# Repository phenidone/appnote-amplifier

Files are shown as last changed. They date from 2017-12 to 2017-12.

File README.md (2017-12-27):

# appnote-amplifier

This is a PCB design for a headphone amplifier based on the example schematic in the LME49600 datasheet.

## Power Supply

You will need a 12VAC or 24VAC centre-tapped transformer.  The simplest/safest option is to use it with
a Class-II (double insulated) accredited 12VAC 0.5A plugpack and not ground any part of this design.

Use Phoenix-style screw terminals.

## Inputs & Outputs

Place a 10K dual-gang A-scale volume pot between the signal source and the inputs to this board.  Use 0.1"-pitch
Phoenix-style screw terminals.

## Thermal

There is a bare patch on the board surrounding the output stage; you can solder a strip of copper
sheet here to act as a heatsink, if that seems to be necessary (almost certainly not).  Note that it will be connected to the negative
rail, so don't let the heatsink touch anything.

## Errata

Rev.A is missing reverse-protection diodes around the regulators.  They are considered best-practise
for cases where the input voltage on a regulator may collapse faster than its output and as such should not be necessary for this design - the regulators should be the only current
drain upon the rectifier capacitors.  They have been added to Rev.B on the basis of paranoia and can be hand-soldered onto the underside of a Rev.A board.

The BOM lists 7812 and 7912 regulators and 12VAC supply, which is more voltage than most headphones require.  For headphones of no more than 64 ohms,
a 7805 and 7905 are enough and will need only a 6VAC transformer.

## License

This hardware design is (C) 2017 William Brodie-Tyrrell and is licensed under the CERN OHL; see cern_ohl_v_1_2.pdf

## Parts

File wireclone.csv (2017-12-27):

Reference | Value | Footprint | Datasheet
P3 | CONN_01X03 | Pin_Headers:Pin_Header_Straight_1x03_Pitch2.54mm
P2 | CONN_01X02 | Pin_Headers:Pin_Header_Straight_1x02_Pitch2.54mm
P4 | CONN_01X02 | Pin_Headers:Pin_Header_Straight_1x02_Pitch2.54mm
FID1 | FIDUCIAL | smd:FID0.5
FID2 | FIDUCIAL | smd:FID0.5
FID4 | FIDUCIAL | smd:FID0.5
FID3 | FIDUCIAL | smd:FID0.5
U1 | LME49720 | Housings_DIP:DIP-8_W7.62mm_Socket
R1 | 1k | Resistors_SMD:R_0805
R9 | 1k | Resistors_SMD:R_0805
R7 | 1k | Resistors_SMD:R_0805
C7 | 1u | Capacitors_SMD:C_0805
R2 | 1M | Resistors_SMD:R_0805
R5 | 1M | Resistors_SMD:R_0805
C3 | 1u | Capacitors_SMD:C_1206
C4 | 1u | Capacitors_SMD:C_1206
C1 | 1u | Capacitors_SMD:C_0805
U4 | LME49600 | power:TO-263-5
U2 | LME49720 | Housings_DIP:DIP-8_W7.62mm_Socket
R3 | 1k | Resistors_SMD:R_0805
R10 | 1k | Resistors_SMD:R_0805
R8 | 1k | Resistors_SMD:R_0805
C8 | 1u | Capacitors_SMD:C_0805
R4 | 1M | Resistors_SMD:R_0805
R6 | 1M | Resistors_SMD:R_0805
C5 | 1u | Capacitors_SMD:C_1206
C6 | 1u | Capacitors_SMD:C_1206
C2 | 1u | Capacitors_SMD:C_0805
C9 | 10u | Capacitors_SMD:C_1206
C10 | 10u | Capacitors_SMD:C_1206
C11 | 10u | Capacitors_SMD:C_1206
C12 | 10u | Capacitors_SMD:C_1206
U3 | LME49600 | power:TO-263-5
D1 | M7 | Diodes_SMD:D_SMA
D2 | M7 | Diodes_SMD:D_SMA
C17 | 1000u | Capacitors_ThroughHole:C_Radial_D16_L25_P7.5
C19 | 1000u | Capacitors_ThroughHole:C_Radial_D16_L25_P7.5
C21 | 100n | Capacitors_SMD:C_0805
C18 | 1000u | Capacitors_ThroughHole:C_Radial_D16_L25_P7.5
C20 | 1000u | Capacitors_ThroughHole:C_Radial_D16_L25_P7.5
C22 | 100n | Capacitors_SMD:C_0805
U5 | LM7812CT | Power_Integrations:TO-220
U6 | LM7912CT | Power_Integrations:TO-220
P1 | CONN_01X03 | Terminals_Phoenix:TerminalBlock_Phoenix_MPT-2.54mm_3pol
D4 | M7 | Diodes_SMD:D_SMA
D3 | M7 | Diodes_SMD:D_SMA
D5 | M7 | Diodes_SMD:D_SMA
D6 | M7 | Diodes_SMD:D_SMA

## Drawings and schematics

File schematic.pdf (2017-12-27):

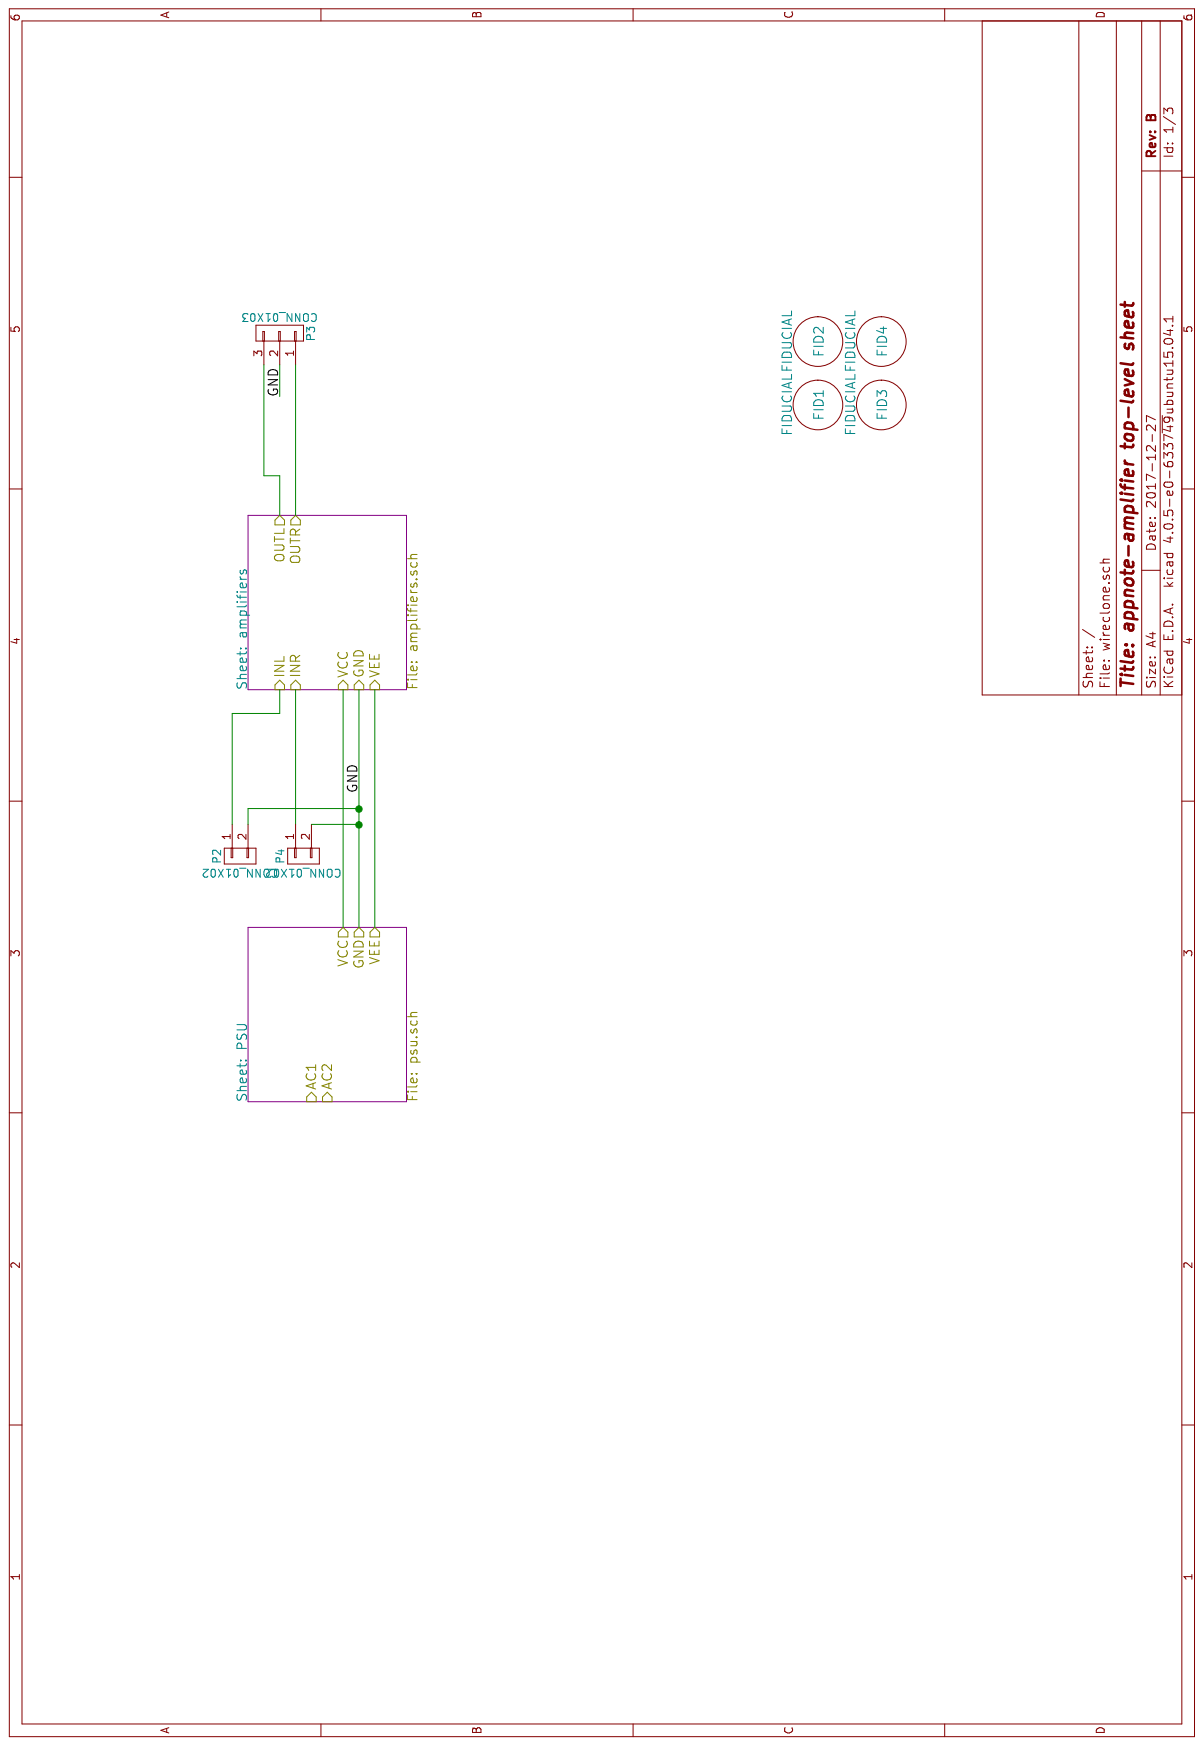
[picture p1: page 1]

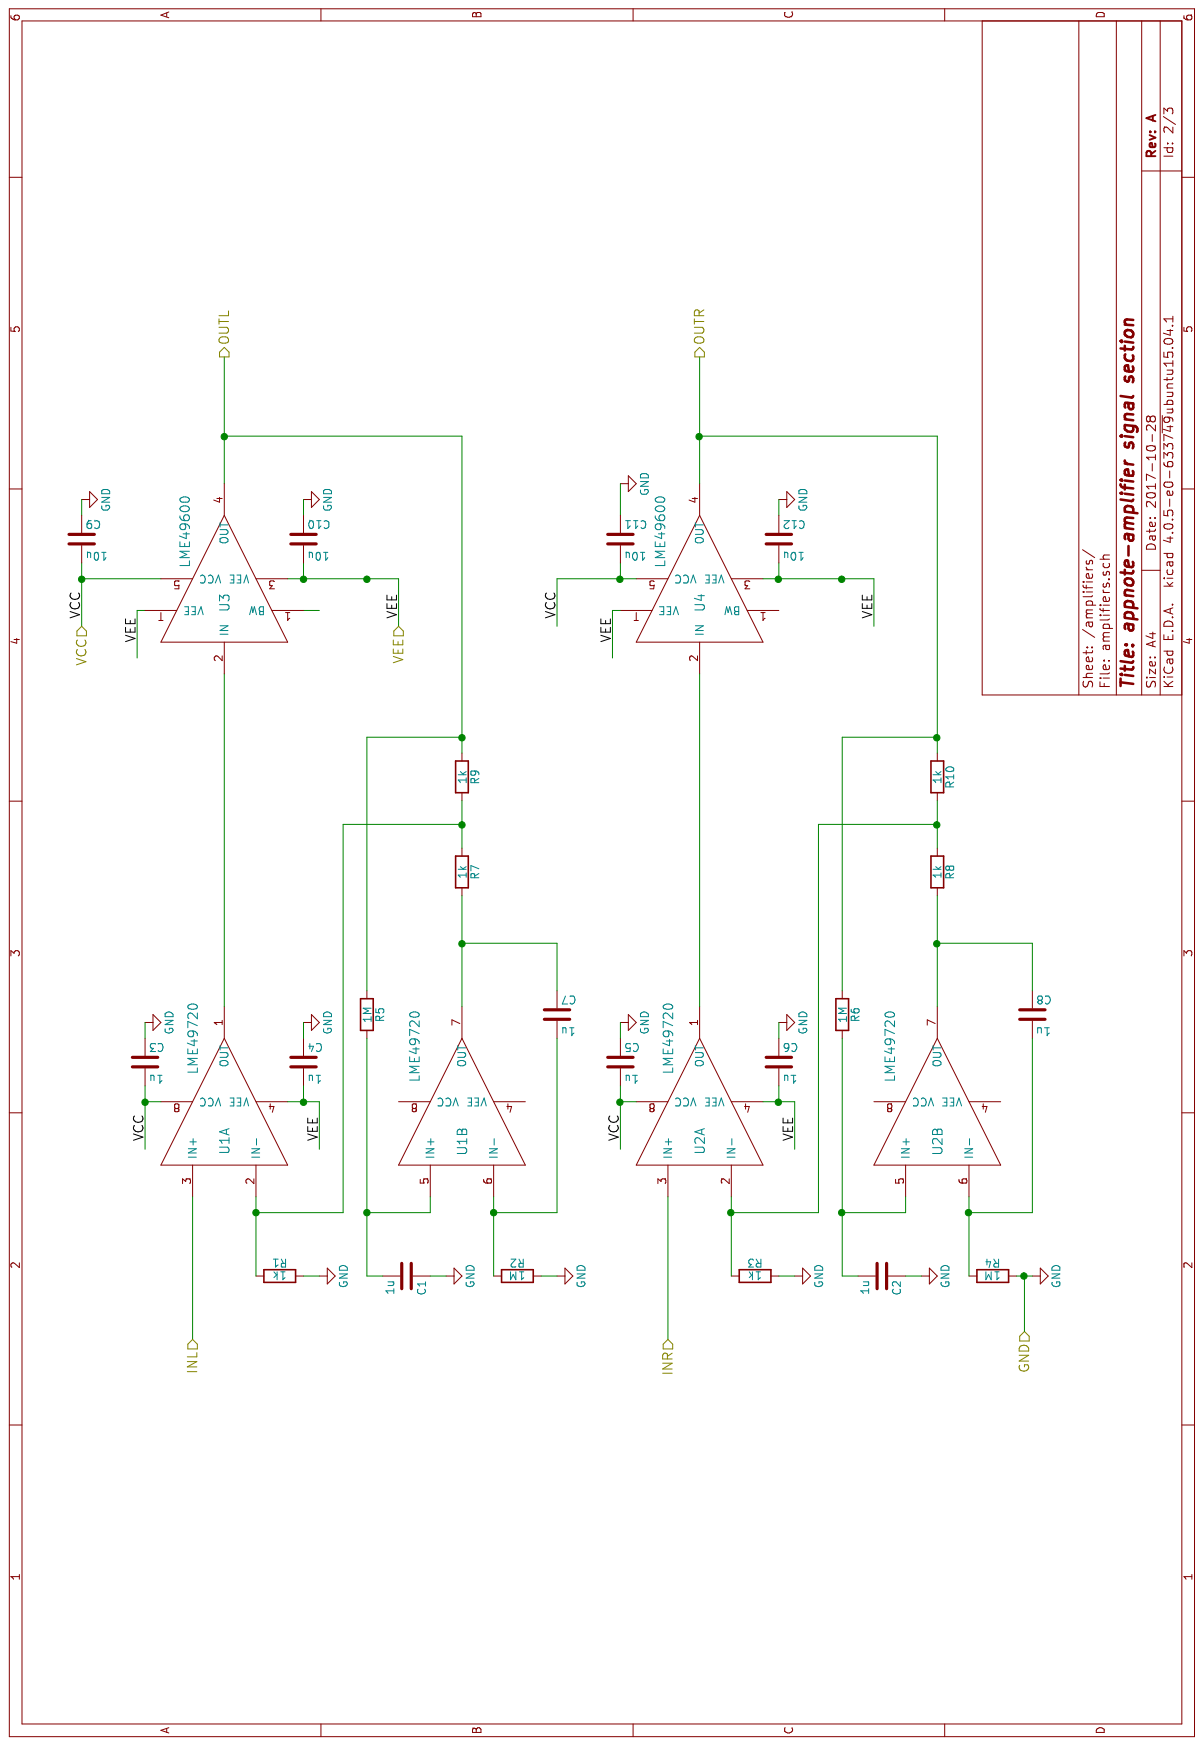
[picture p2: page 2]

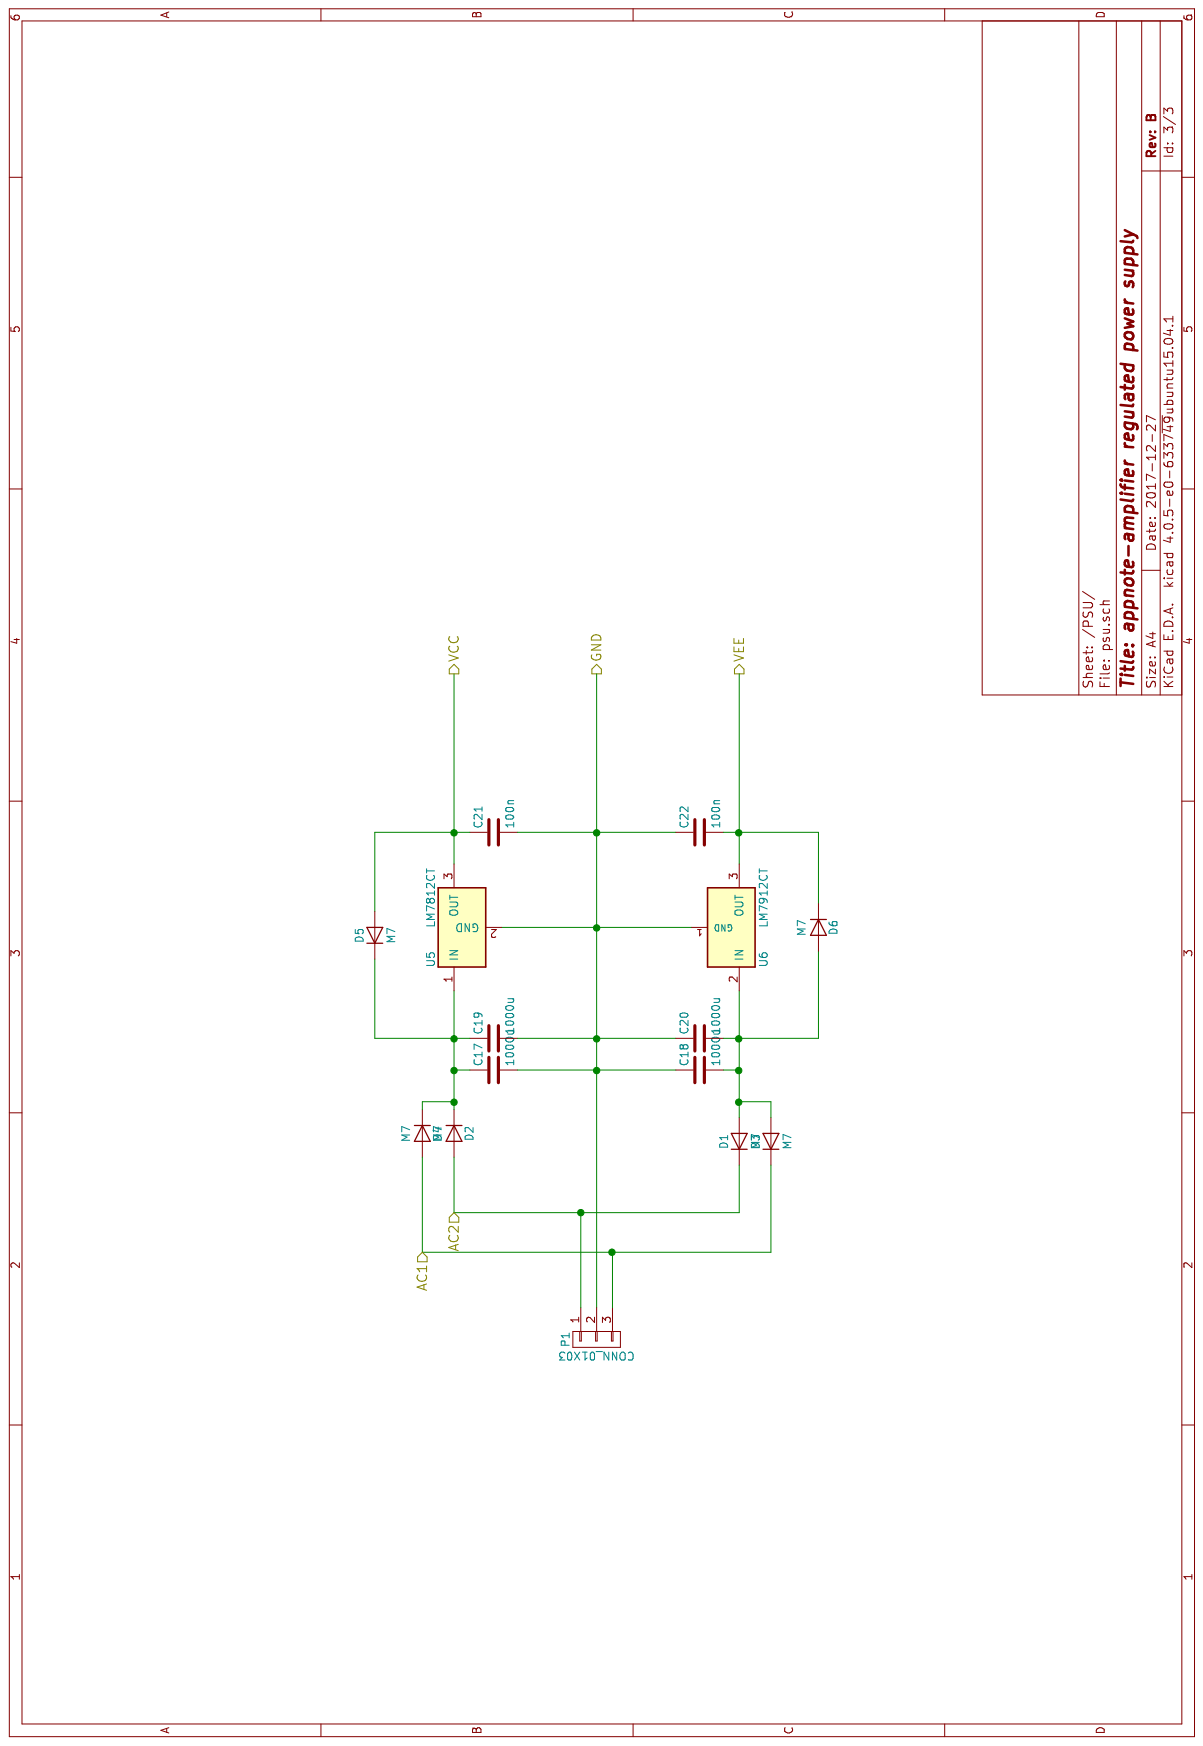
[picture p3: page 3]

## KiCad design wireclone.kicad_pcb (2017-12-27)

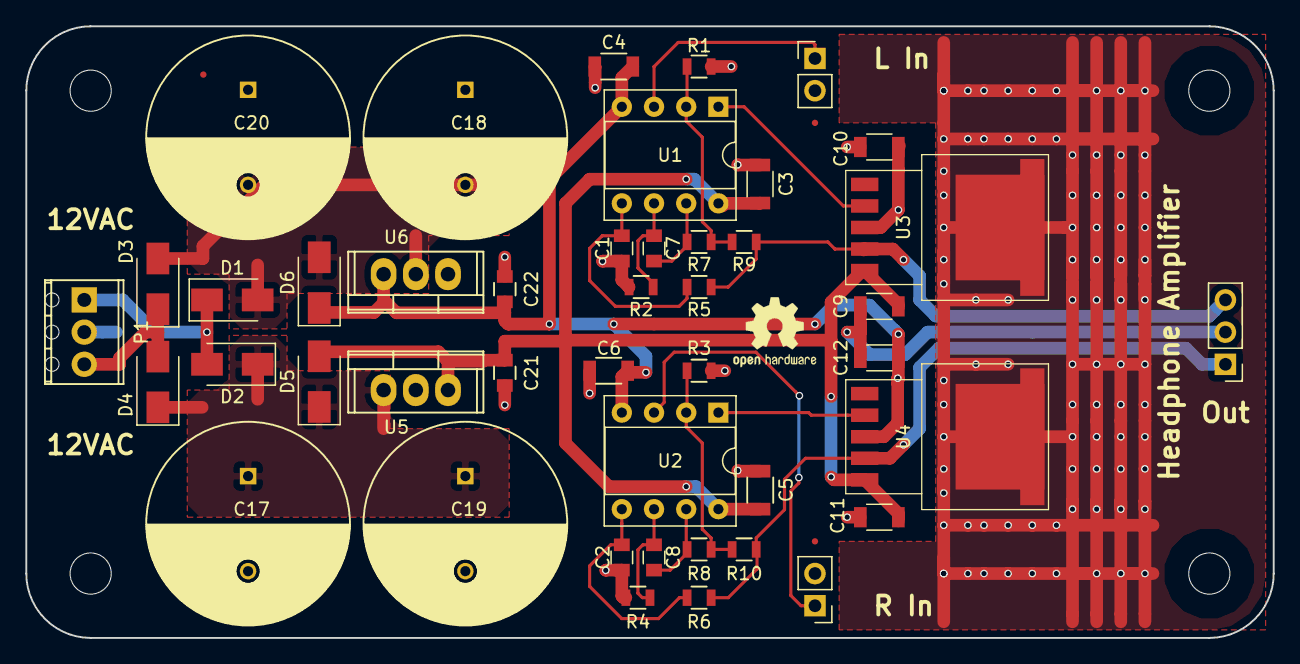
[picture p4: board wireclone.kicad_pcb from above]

Board: 2 copper layers, 98.4 x 48.3 mm, 48 parts (0 on the bottom side), 21 nets.

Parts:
C1, C2, C7, C8: 1u; C_0805
C3, C4, C5, C6: 1u; C_1206
C9, C10, C11, C12: 10u; C_1206
C17, C18, C19, C20: 1000u; C_Radial_D16_L25_P7.5
C21, C22: 100n; C_0805
D1, D2, D3, D4, D5, D6: M7; D_SMA
FID1, FID2, FID3, FID4: FIDUCIAL; FID0.5
P1: CONN_01X03; TerminalBlock_Phoenix_MPT-2.54mm_3pol
P2, P4: CONN_01X02; Pin_Header_Straight_1x02_Pitch2.54mm
P3: CONN_01X03; Pin_Header_Straight_1x03_Pitch2.54mm
R1, R3, R7, R8, R9, R10: 1k; R_0805
R2, R4, R5, R6: 1M; R_0805
U1, U2: LME49720; DIP-8_W7.62mm_Socket
U3, U4: LME49600; TO-263-5
U5: LM7812CT; TO-220
U6: LM7912CT; TO-220

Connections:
/PSU/AC1: D3.1, D4.2, P1.3
/PSU/AC2: D1.1, D2.2, P1.1
/PSU/VCC: C3.2, C5.2, C9.2, C11.2, C21.1, D5.2, U1.8, U2.8, U3.5, U4.5, U5.3
/PSU/VEE: C4.2, C6.2, C10.2, C12.2, C22.2, D6.1, U1.4, U2.4, U3.3, U3.T, U4.3, U4.T, U6.3
/amplifiers/INL: P2.1, U1.3
/amplifiers/INR: P4.1, U2.3
/amplifiers/OUTL: P3.3, R5.1, R9.1, U3.4
/amplifiers/OUTR: P3.1, R6.1, R10.1, U4.4
GND: C1.1, C2.1, C3.1, C4.1, C5.1, C6.1, C9.1, C10.1, C11.1, C12.1, C17.2, C18.1, C19.2, C20.1, C21.2, C22.1, P1.2, P2.2, P3.2, P4.2, R1.2, R2.2, R3.2, R4.2, U5.2, U6.1
unnamed: C1.2, R5.2, U1.5
unnamed: C2.2, R6.2, U2.5
unnamed: C7.1, R7.2, U1.7
unnamed: C7.2, R2.1, U1.6
unnamed: C8.1, R8.2, U2.7
unnamed: C8.2, R4.1, U2.6
unnamed: C17.1, C19.1, D2.1, D4.1, D5.1, U5.1
unnamed: C18.2, C20.2, D1.2, D3.2, D6.2, U6.2
unnamed: R1.1, R7.1, R9.2, U1.2
unnamed: R3.1, R8.1, R10.2, U2.2
unnamed: U1.1, U3.2
unnamed: U2.1, U4.2

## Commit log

2016-12-07 begin schematic drafting - follows LME49600 datasheet
    [wireclone.kicad_pcb, wireclone.sch]
2017-10-24 checked in all subsheets
    [wireclone.kicad_pcb, wireclone.sch]
2017-10-24 second try adding
    [amplifiers.sch, psu.sch, xformer.sch]
2017-10-25 did most of the layout
    [amplifiers.sch, psu.sch, wireclone.kicad_pcb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]
2017-10-25 moved output to end, stitched thermal plane
    [wireclone.kicad_pcb, wireclone.sch]
2017-10-26 complete layout drafted
    [amplifiers.sch, wireclone.kicad_pcb, wireclone.sch]
2017-10-26 shortened board
    [wireclone-B.Cu.gbr, wireclone-B.Mask.gbr, wireclone-B.SilkS.gbr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]
2017-10-26 added fiducials
    [wireclone-B.Cu.gbr, wireclone-B.Mask.gbr, wireclone-B.SilkS.gbr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]
2017-10-28 cleanup, rev.a as manufactured
    [wireclone-B.Cu.gbr, wireclone-B.Mask.gbr, wireclone-B.SilkS.gbr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]
2017-10-28 updated readme (grounding)
2017-10-28 added PDF of schematic
    [amplifiers.sch, psu.sch, wireclone.sch]
2017-12-27 added reverse protection diodes to regulators, bumped to Rev.B
    [amplifiers.sch, psu.sch, wireclone.csv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]
2017-12-27 updated schematic.pdf
2017-12-27 updated schematic.pdf and README
2017-12-27 shrunk power connector, made all diodes same type, mentioned 5+5V operation in errata
    [psu.sch, wireclone.csv, wireclone.kicad_pcb]
